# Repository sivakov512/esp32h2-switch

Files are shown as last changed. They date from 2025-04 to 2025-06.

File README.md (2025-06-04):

# Matter-Enabled Thread Switch on ESP32-H2

This repository contains a minimal Matter + Thread project targeting the **ESP32-H2** MCU. It controls a relay with the aim of managing a water heater or similar appliance. The project is written in **C++20** (with some C code) using the **ESP-IDF** and **ESP-Matter** frameworks.

## Overview
* **Core MCU**: [ESP32-H2](https://www.espressif.com/en/products/socs/esp32-h2)
* **Protocol**: Matter over Thread
* **Relay Control**: GPIO27
* **Status LED**: GPIO26
* **Language**: C++20 & C
* **Thread Config**: Enabled by default in sdkconfig.defaults
* **Commissioning Data**: Stored in a factory partition (fctry) at 0x3E0000

## Hardware

### Board Overview

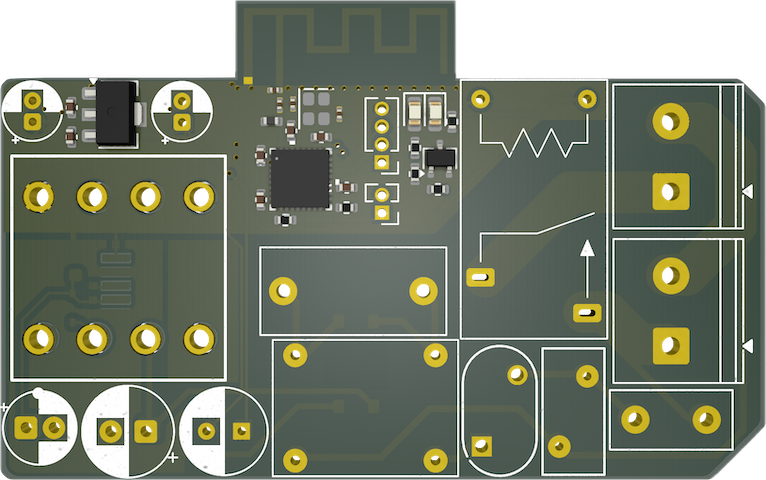
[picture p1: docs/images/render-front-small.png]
3D Render of the Board front-side

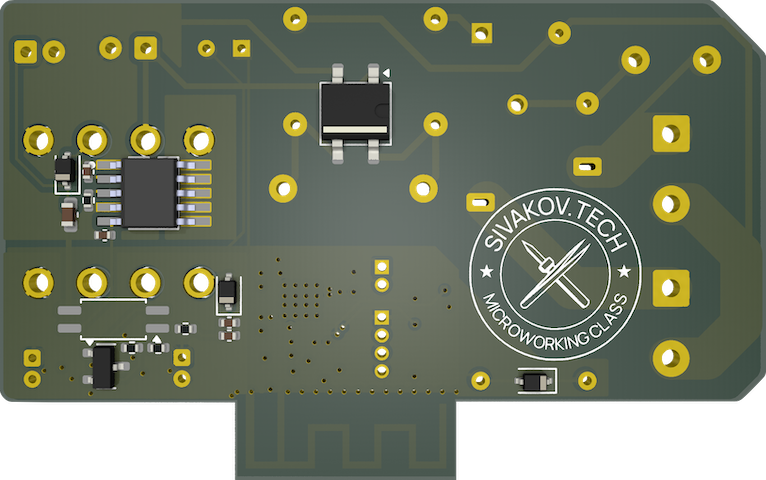
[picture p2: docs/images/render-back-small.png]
3D Render of the Board back-side


The ESP32-H2 Switch is designed for controlling high-voltage appliances with safety in mind. The board features:

- Compact dimensions for easy installation
- Clearly labeled connectors and indicators
- High-quality relay rated for 220V and up to 10A current

### Dimensions & Mounting

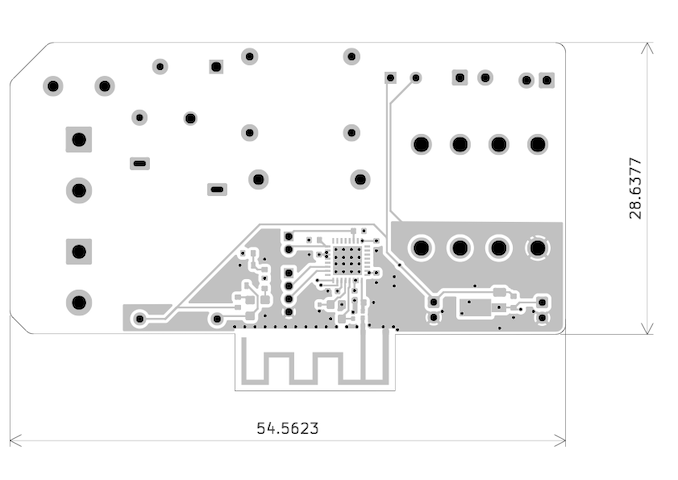
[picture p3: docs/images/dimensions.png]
Board Dimensions


The board measures 54.56mm x 28.64mm and is designed to be installed inside existing devices or enclosures.

### Pinout & Connections

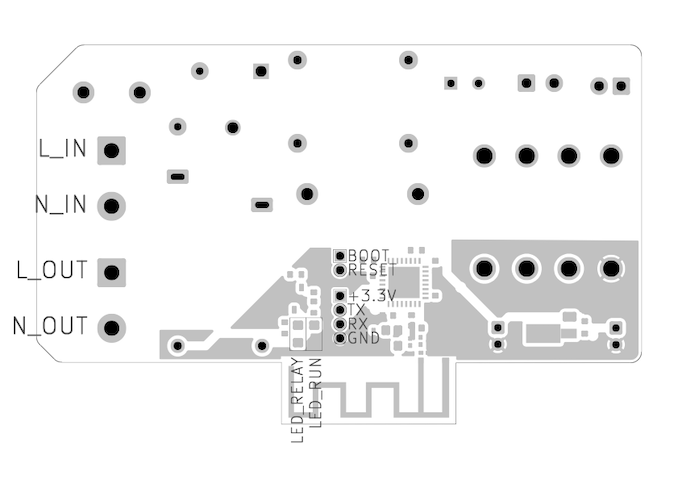
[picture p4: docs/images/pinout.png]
Board Pinout and Connections


Important connections:
- **AC Input/Output**: Screw terminals on the left side for line (phase) and neutral input and output
- **Status LEDs**: Located at the bottom above the antenna
  - LED_RELAY: Indicates relay activation status
  - LED_RUN: Indicates device operational status
- **Debug Headers**: UART pins for flashing and debugging (from top to bottom: +3.3V, TX, RX, GND)
- **Control Pins**: BOOT and RESET pins (must be manually shorted to GND to activate)

**Safety Note**: All power lines are routed on the bottom layer of the PCB. Exercise extreme caution during installation to avoid contact with these traces when connected to mains power.

### Hardware Variants
The project includes KiCad PCB and schematic files in the `hardware/` directory with two variants:
- `smd/`: Surface-mounted component design (more compact)
- `tht/`: Through-hole component design (easier to assemble manually)

**Note**: The hardware designs depend on a custom KiCad component library. To open and edit the schematics:
1. Install the component library from https://github.com/sivakov512/kicad-library
2. Follow the installation instructions in that repository

## Software

### Requirements
1. [ESP-IDF 5.4](https://github.com/espressif/esp-idf/tree/release/v5.4)
    - Follow the official ESP-IDF [documentation](https://docs.espressif.com/projects/esp-idf/en/stable/esp32h2/get-started/index.html#installation) for installation and setup.
2. [ESP-Matter 1.4](https://github.com/espressif/esp-matter/tree/release/v1.4)
    - Refer to the ESP-Matter repo for detailed instructions on integrating Matter into ESP-IDF.

### Setup

1. Clone this repository alongside your ESP-IDF and ESP-Matter installations.
2. Ensure that `sdkconfig.defaults` includes the necessary Thread and Matter configurations for ESP32-H2.
3. Verify that `GPIO27` is free to drive your relay hardware and `GPIO26` for the status LED.

### Project Structure
Typical ESP-IDF directory layout:
```project_root/
├── CMakeLists.txt
├── sdkconfig.defaults
├── main/
│   ├── main.cpp
│   └── ...
├── hardware/
│   ├── smd/
│   └── tht/
├── docs/
│   └── images/
└── partitions.csv
```

### Building

1. Set the target to **esp32h2**:
```sh
idf.py set-target esp32h2
```

2. Build the firmware:
```sh
idf.py build
```

3. Flash to your device (initial firmware, excluding commissioning info):
```sh
idf.py flash
```

### Commissioning Data (Factory Partition)

To avoid using test keys in production, generate your own commissioning data and flash it to the `fctry` partition at address `0x3E0000`.
* We recommend using [ESP Matter Manufacturing Tool (mfg_tool)](https://github.com/espressif/esp-matter-tools/tree/main/mfg_tool).
* Example command (using test keys) for building provisioning data:
```sh
esp-matter-mfg-tool -v 0xFFF2 -p 0x8001 \
  --vendor-name "Nikita Sivakov" \
  --product-name "Switch" \
  -cd $MATTER_SDK_PATH/credentials/test/certification-declaration/Chip-Test-CD-FFF2-8001.der
```
This generates a binary that contains the necessary credentials for Matter commissioning.

#### Flashing the Commissioning Binary
Once the binary is generated, flash it to `0x3E0000`:
```sh
esptool.py -p <DEVICE_PORT> write_flash 0x3E0000 <PATH_TO_GENERATED_BINARY>
```
*Replace `<DEVICE_PORT>` (e.g. `COM3` or `/dev/ttyUSB0`) and `<PATH_TO_GENERATED_BINARY>` with your actual values.*

## Usage and Operation

### Initial Setup
1. Mount the board in a suitable enclosure.
2. Connect the power and load wires according to the pinout diagram.
3. Power up the board.

### Software Setup
1. Join a Thread network and start the Matter commissioning process.
2. Use a Matter controller (Apple Home, Google Home, or other Matter-compatible hub) to add the device.
3. Once commissioned, toggle the relay through Matter commands.

### Status Indicators
- **LED_RUN**: Indicates that the device is operating properly
- **LED_RELAY**: Indicates when the relay is activated

## Contributing
* For any issues, suggestions, or feature requests, please open an [issue](../../issues).
* Pull requests with improvements or bug fixes are welcome.

## Safety Warning

**IMPORTANT**: This device controls high-voltage appliances. Improper installation may result in electric shock or fire hazards.

- Always disconnect power before installation or maintenance
- Install in a suitable enclosure
- Follow all local electrical codes and regulations
- If you're not qualified to work with high-voltage equipment, consult a licensed electrician

---

**Note**: This project is provided as-is for demonstration purposes. Always exercise caution when dealing with high-voltage equipment such as water heaters.

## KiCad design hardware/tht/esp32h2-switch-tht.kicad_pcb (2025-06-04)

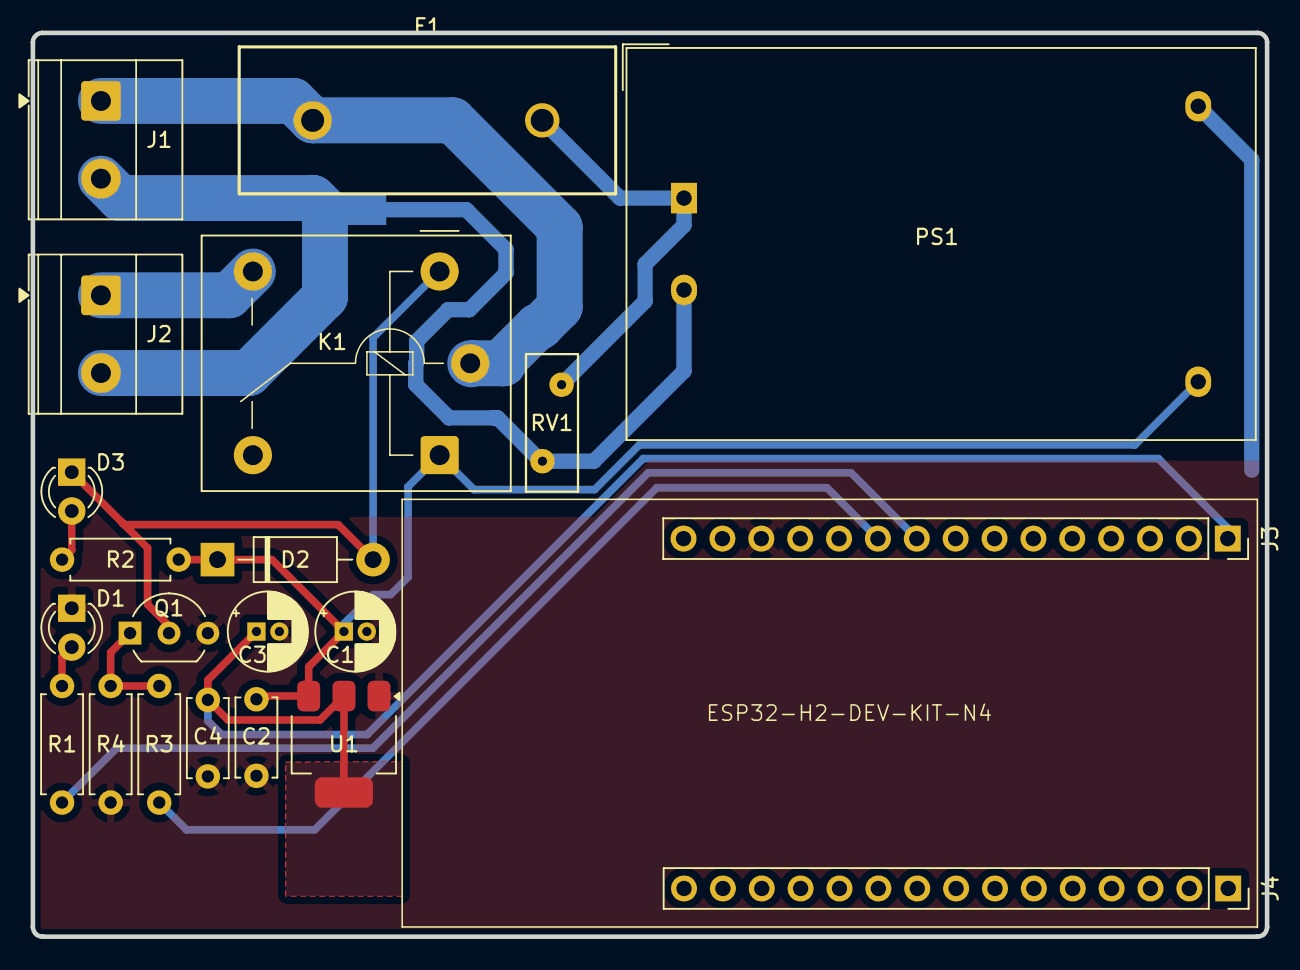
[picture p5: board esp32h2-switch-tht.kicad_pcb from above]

Board: 2 copper layers, 80.6 x 59.1 mm, 22 parts (1 on the bottom side), 14 nets.

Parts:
C1, C3: 22u; CP_Radial_D5.0mm_P1.50mm
C2, C4: 100n; C_Disc_D5.0mm_W2.5mm_P5.00mm
D1: Blue, 3V, 10mA; LED_D3.0mm
D2: 40V, 1A; D_DO-41_SOD81_P10.16mm_Horizontal
D3: Red, 2V, 10mA; LED_D3.0mm
F1: T250mA 250V; FuseHolder_THT_5x20mm_PTF76_RM15mm
J1, J2: Screw_Terminal_01x02; TerminalBlock_Phoenix_MKDS-1,5-2-5.08_1x02_P5.08mm_Horizont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
J3, J4: Conn_01x15; PinSocket_1x15_P2.54mm_Vertical
K1: SPDT, 5V 72R, 10A 250VAC; Relay_SPDT_Relpol-RM51
NT1: NetTie_2; NetTie-2_SMD_Pad2.0mm
PS1: HLK-5M05; Converter_ACDC_Hi-Link_HLK-5Mxx
Q1: NPN, 40V, 500mA; TO-92_Inline_Wide
R1: 220R; R_Axial_DIN0207_L6.3mm_D2.5mm_P7.62mm_Horizontal
R2, R3: 330R; R_Axial_DIN0207_L6.3mm_D2.5mm_P7.62mm_Horizontal
R4: 10k; R_Axial_DIN0207_L6.3mm_D2.5mm_P7.62mm_Horizontal
RV1: 275V; RV_Disc_D9mm_W3.4mm_P5mm
U1: LM1117MP-3.3; SOT-223-3_TabPin2

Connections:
+3.3V: C3.1, C4.1, J3.1, U1.2 (VO)
+5V: C1.1, C2.1, D2.1 (K), K1.A2, PS1.4 (+Vout), R2.1, U1.3 (VI)
/LED_RELAY: D3.2 (A), R2.2
/LED_RUN: D1.2 (A), R1.1
/L_OUT: J2.1, K1.14
/RELAY_COIL: D2.2 (A), D3.1 (K), K1.A1, Q1.2 (C)
/RELAY_CTRL: J3.10, R3.1
GND: C1.2, C2.2, C3.2, C4.2, D1.1 (K), J3.13, PS1.3 (-Vout), Q1.3 (E), R4.2, U1.1 (GND)
L: F1.2, PS1.1 (AC/L), RV1.1
L_IN: F1.1, J1.1, K1.11
N: NT1.2, PS1.2 (AC/N), RV1.2
N_IN: J1.2, J2.2, NT1.1
unnamed: J3.9, R1.2
unnamed: Q1.1 (B), R3.2, R4.1

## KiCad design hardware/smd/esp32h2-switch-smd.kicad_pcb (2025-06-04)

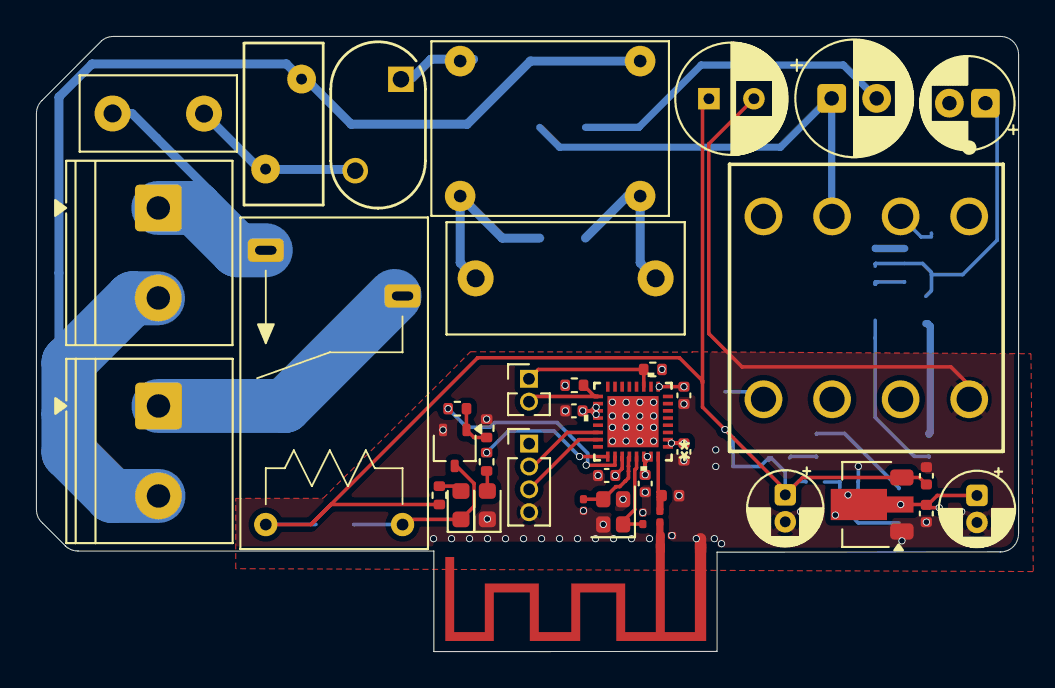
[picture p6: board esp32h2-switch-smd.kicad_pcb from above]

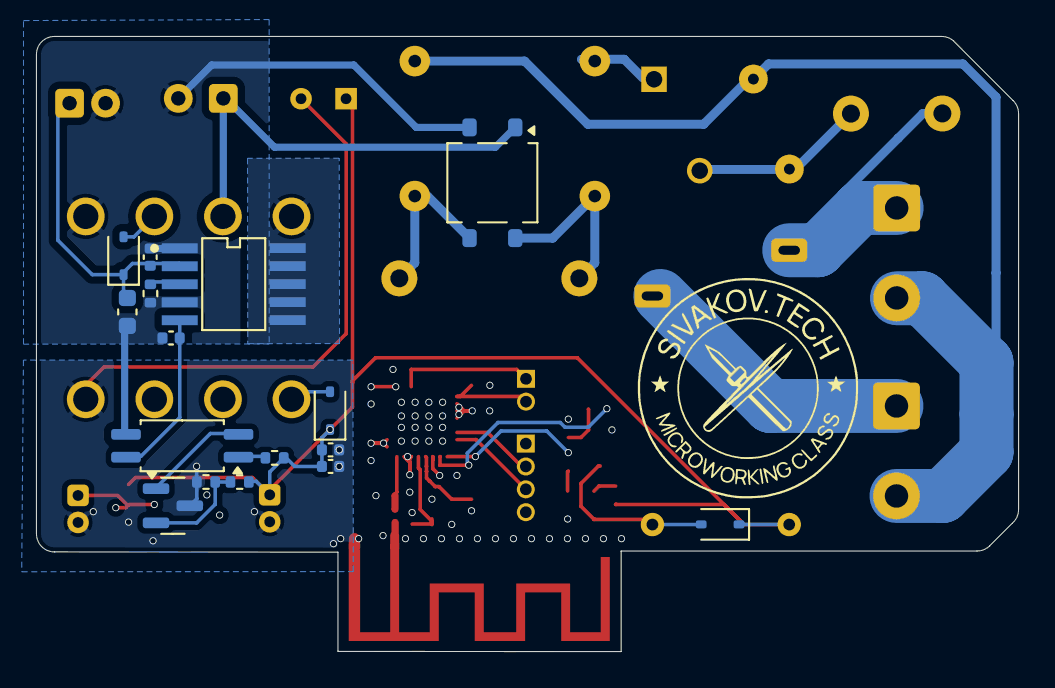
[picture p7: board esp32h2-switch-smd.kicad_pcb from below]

Board: 4 copper layers, 54.6 x 34.2 mm, 59 parts (18 on the bottom side), 33 nets.

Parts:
AE1: Antenna_Chip; Antenna_PCB_Espressif_2.4GHz_Right
C1, C5: 22u 10V; CP_Radial_D4.0mm_P1.50mm
C2, C6, C10, C14, C16, C19, C20, C22: 100n 10V X7R; C_0402_1005Metric
C3: 220n 275V X2; C_Rect_L13.0mm_W6.0mm_P10.00mm_FKS3_FKP3_MKS4
C4: 4.7u 400V; CP_Radial_D6.3mm_P2.50mm
C7: 2.2n 50V X7R; C_0402_1005Metric
C8: 470u 10V; CP_Radial_D6.0mm_P2.50mm
C9: 22u 35V; CP_Radial_D5.0mm_P2.00mm
C11: 100n 35V X7R; C_0603_1608Metric
C12: 1n 10V X7R; C_0402_1005Metric
C13: 2.2n 35V X7R; C_0402_1005Metric
C15: 5.6p C0G; C_0201_0603Metric
C17, C21: 8p 10V C0G; C_0201_0603Metric
C18: 2.2p C0G; C_0201_0603Metric
D1: 1A 600V; TO-269AA
D2, D3, D4: 40V 1A; D_SOD-323
D5: Blue, 3V, 10mA; LED_0603_1608Metric
D6: Red, 2V, 10mA; LED_0603_1608Metric
F1: T500mA 250V; Fuse_Littelfuse_395Series
FL1: 2×4.7m ≥0.3A ≤2R; TDK_B82720K_Vertical_13x9.5mm_P10x7.5mm
J1, J2: Screw_Terminal_01x02; TerminalBlock_Phoenix_PT-1,5-2-5.0-H_1x02_P5.00mm_Horizontal
J5: UART; PinHeader_1x04_P1.27mm_Vertical
J6: Conn_01x02_Pin; PinHeader_1x02_P1.27mm_Vertical
K1: SPST, 5V 72R, 10A 250VAC; OJ_SH_105HM_SPST
L1: 3.9 nH; L_0402_1005Metric
NT1, NT2: NetTie_2; NetTie_2_D0.5_P4.0
Q1: NPN, 40V, 500mA; SOT-323_SC-70
R1: 30k; R_0402_1005Metric
R2: 470R; R_0402_1005Metric
R3, R4, R7, R9, R10: 10k; R_0402_1005Metric
R5, R8: 330R; R_0402_1005Metric
R6: 220R; R_0402_1005Metric
RV1: 275V; RV_Disc_D9mm_W4.4mm_P5mm
T1: Wurth 750370423; Wurth_750370423_THT_E13
TH1: 10R 25C; NTC10D_7_Disc_D7.0mm_P5.0mm
U1: LM1117F-3.3; SOT-89-3
U2: VIPER06; STMicroelectronics_VIPER06_SSO10
U3: EL3H7; SSOP-4_4.4x2.6mm_P1.27mm
U4: TL431; SOT-23
U5: ESP32-H2; TQFN_32_1EP_4x4mm_P0.4mm_EP2.4x2.4mm_Compact
Y1: 32MHz ±10ppm CL8pF; Crystal_SMD_2016-4Pin_2.0x1.6mm

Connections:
+3.3V: C5.1, C6.1, C14.2, C16.2, C19.2, C20.2, C22.2, J5.1, R7.2, R10.2, U1.2 (VO), U5.1 (VDD3P3), U5.2 (VDD3P3), U5.9 (VDDPST1), U5.18 (VBAT), U5.19 (VDDA_PMU), U5.20 (VDDPST1), U5.27 (VDD3P3), U5.30 (VDD3P3), U5.31 (VDD3P3)
+5V: C1.1, C2.1, C8.1, C10.1, C12.1, D3.1 (K), D4.1 (K), K1.A1, R2.2, R3.1, R5.1, U1.3 (VI)
/Control unit/LED_RELAY: D6.2 (A), R5.2
/Control unit/LED_RUN: R6.2, U5.25 (GPIO26)
/Control unit/RELAY_COIL: D4.2 (A), D6.1 (K), K1.A2, Q1.3 (C)
/Control unit/RELAY_CTRL: R8.1, U5.26 (GPIO27)
/Control unit/RF: C15.2, L1.1, U5.32 (ANT)
/Control unit/RX: J5.3, U5.23 (U0TXD)
/Control unit/TX: J5.2, U5.22 (U0RXD)
/N_IN: J1.2, J2.2, NT2.1
/Power supply/DRAIN: T1.4, U2.6 (DRAIN), U2.7 (DRAIN), U2.8 (DRAIN), U2.9 (DRAIN), U2.10 (DRAIN)
/Power supply/VRECT: C4.1, D1.1 (+), T1.3
BOOT: J6.1, R7.1, U5.11 (GPIO9)
GND: AE1.2 (PCB_Trace), C1.2, C2.2, C5.2, C6.2, C8.2, C10.2, C12.2, C14.1, C16.1, C17.2, C18.1, C19.1, C20.1, C21.1, C22.1, D5.1 (K), J5.4, L1.2, Q1.2 (E), R4.2, R9.2, T1.8, U1.1 (GND), U4.3 (A), U5.33 (GND), Y1.2, Y1.4
GND_P: C4.2, C7.2, C9.2, C11.2, C13.2, D1.2 (-), R1.2, T1.1, U2.1 (GND), U2.4 (FB), U3.3
L: C3.1, D1.4, F1.1, F1.2, FL1.1, FL1.4, NT1.2, RV1.1, TH1.1, TH1.2
L_IN: J1.1, K1.14, NT1.1
L_OUT: J2.1, K1.13
N: C3.2, D1.3, FL1.2, FL1.3, NT2.2, RV1.2
unnamed: AE1.1 (FEED), C15.1, C18.2
unnamed: D2.2 (A), T1.2
unnamed: C9.1, C11.1, C13.1, D2.1 (K), U2.2 (VDD)
unnamed: D3.2 (A), T1.5
unnamed: D5.2 (A), R6.1
unnamed: Q1.1 (B), R8.2, R9.1
unnamed: R2.1, U3.1
unnamed: C7.1, U2.5 (COMP), U3.4
unnamed: R1.1, U2.3 (LIM)
unnamed: U3.2, U4.1 (K)
unnamed: R3.2, R4.1, U4.2 (REF)
unnamed: C21.2, U5.28 (XTAL_N), Y1.3
unnamed: C17.1, U5.29 (XTAL_P), Y1.1
RESET: J6.2, R10.1, U5.17 (CHIP_EN)

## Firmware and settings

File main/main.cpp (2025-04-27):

#include <app/server/Server.h>
#include <esp_err.h>
#include <esp_log.h>
#include <esp_matter.h>
#include <nvs_flash.h>
#include <platform/ESP32/OpenthreadLauncher.h>

#include "common.h"
#include "driver.h"
#include "matter.h"

static const uint8_t kThreadQueueSize = 10;

static Driver g_driver;

extern "C" void app_main() {  // NOLINT
  esp_err_t err;

  err = g_driver.Init();
  ABORT_APP_ON_FAILURE(err == ESP_OK, "Failed to initialize driver, err: %d",
                       err);

  nvs_flash_init();

  esp_openthread_platform_config_t config = {
      .radio_config = {.radio_mode = RADIO_MODE_NATIVE},
      .host_config = {.host_connection_mode = HOST_CONNECTION_MODE_NONE},
      .port_config =
          {
              .storage_partition_name = "nvs",
              .netif_queue_size = kThreadQueueSize,
              .task_queue_size = kThreadQueueSize,
          },
  };
  set_openthread_platform_config(&config);

  err = StartMatterStack(&g_driver);
  ABORT_APP_ON_FAILURE(err == ESP_OK, "Failed to start Matter, err: %d", err);

  err = g_driver.SetLedState(true);
  ABORT_APP_ON_FAILURE(err == ESP_OK, "Failed to set LED state, err: %d", err);
}

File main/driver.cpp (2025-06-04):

#include <driver/gpio.h>
#include "soc/gpio_num.h"

#include "driver.h"

static const gpio_num_t kRelayGPIO = GPIO_NUM_27;
static const gpio_num_t kLedGPIO = GPIO_NUM_26;

Driver::Driver() : relay_gpio_(kRelayGPIO), led_gpio_(kLedGPIO) {}

esp_err_t Driver::Init() {
  gpio_config_t gpio_conf = {
      .pin_bit_mask = (1ULL << relay_gpio_) | (1ULL << led_gpio_),
      .mode = GPIO_MODE_OUTPUT,
      .pull_up_en = GPIO_PULLUP_DISABLE,
      .pull_down_en = GPIO_PULLDOWN_DISABLE,
      .intr_type = GPIO_INTR_DISABLE,
  };
  return gpio_config(&gpio_conf);
}

esp_err_t Driver::SetRelayState(bool val) {
  return gpio_set_level(relay_gpio_, static_cast<uint32_t>(val));
}

esp_err_t Driver::SetLedState(bool val) {
  return gpio_set_level(led_gpio_, static_cast<uint32_t>(val));
}

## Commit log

2025-02-12 New project boilerplate
    [partitions.csv]
2025-02-16 Implement thread switch
2025-04-27 KiCad schemas
    [esp32h2-switch.kicad_pcb, esp32h2-switch.kicad_sch]
2025-04-27 Replace devkit on schema with header pings
    [esp32h2-switch.kicad_sch]
2025-04-27 ERC checks
    [esp32h2-switch.kicad_sch]
2025-04-27 Add footprints to schematic
    [esp32h2-switch.kicad_sch]
2025-04-27 Do not track kicad projects settings
2025-04-27 Ignore autosave files (so tired of huge amount of files that don't need to be tracked)
2025-04-27 PCB schematic
    [esp32h2-switch.kicad_pcb, esp32h2-switch.kicad_sch]
2025-04-27 Fix nets due to checks
    [esp32h2-switch.kicad_pcb, esp32h2-switch.kicad_sch]
2025-04-27 Better arragement components + more copper fields
    [esp32h2-switch.kicad_pcb]
2025-04-27 Add LED control to driver
2025-04-27 Better layout for hand soldering
    [esp32h2-switch.kicad_pcb, esp32h2-switch.kicad_sch]
2025-04-27 Add two calibration vias to the PCB layout
    [esp32h2-switch.kicad_pcb]
2025-04-27 Fix footprints and improve layout for hand soldering
    [esp32h2-switch.kicad_pcb, esp32h2-switch.kicad_sch]
2025-06-04 Replace HLK block with SMPS
    [esp32h2-switch.kicad_sch]
2025-06-04 Improve layout a lot
    [esp32h2-switch.kicad_sch]
2025-06-04 Reorganize KiCad project into hardware directory
    [esp32h2-switch-tht.kicad_pcb, esp32h2-switch-tht.kicad_sch]
2025-06-04 Update some project definitions and exclude backups from tracking
    [esp32h2-switch-tht.kicad_pcb, esp32h2-switch-tht.kicad_sch]
2025-06-04 Separate schematics into two sheets. And make them done, yep
    [control_unit.kicad_sch, esp32h2-switch-smd.kicad_pcb, esp32h2-switch-smd.kicad_sch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]
2025-06-04 Add capacitor specifications, change capacity around crystal
    [control_unit.kicad_sch, power_supply.kicad_sch]
2025-06-04 Properly layout GND-fed antenna
    [control_unit.kicad_sch]
2025-06-04 Drop all tht legacy footprints
    [esp32h2-switch-smd.kicad_sch, power_supply.kicad_sch]
2025-06-04 Assign footprints and JLC numbers (plus minor changes)
    [control_unit.kicad_sch, esp32h2-switch-smd.kicad_sch, power_supply.kicad_sch]
2025-06-04 Bill of materials
    [bom.csv]
2025-06-04 Complete PCB and schematics after fucking a lot of iterations
    [bom.csv, control_unit.kicad_sch, esp32h2-switch-smd.kicad_pcb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]
2025-06-04 Rename JLCPCB property to LCSC PN across schematic files
    [control_unit.kicad_sch, esp32h2-switch-smd.kicad_pcb, esp32h2-switch-smd.kicad_sch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]
2025-06-04 Update library paths from KiCadX to PCM_SKC
    [control_unit.kicad_sch, power_supply.kicad_sch]
2025-06-04 Relink symbols and footprints to new lib and fix few errors
    [control_unit.kicad_sch, esp32h2-switch-smd.kicad_pcb, esp32h2-switch-smd.kicad_sch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]
2025-06-04 Added logo on silkscreen
    [esp32h2-switch-smd.kicad_pcb]
2025-06-04 Make vias a bit bigger because of JLCPCB prices and change out-of-stock component
    [esp32h2-switch-smd.kicad_pcb, power_supply.kicad_sch]
2025-06-04 Update GPIO pin assignments for relay and LED
2025-06-04 Add a user layer with pinout
    [esp32h2-switch-smd.kicad_pcb]
2025-06-05 Fix typo in capacitors for oscillator
    [control_unit.kicad_sch]
